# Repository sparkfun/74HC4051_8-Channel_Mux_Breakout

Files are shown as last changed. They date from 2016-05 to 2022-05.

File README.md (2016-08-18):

SparkFun Multiplexer Breakout - 8 Channel (74HC4051)
========================================

SparkFun Multiplexer Breakout - 8 Channel (74HC4051) (https://www.sparkfun.com/products/13906)

[*SparkFun Multiplexer Breakout - 8 Channel (74HC4051) (SKU)*](https://www.sparkfun.com/products/13906)

The SparkFun Multiplexer Breakout provides access to all pins and features of the 74HC4051, an 8-channel analog multiplexer/demultiplexer. The 74HC4051 allows you to turn four I/O pins into eight multi-functional, individually-selectable signals, which can be used do everything from driving eight LEDs to monitoring eight potentiometers.

Repository Contents
-------------------

* **/Firmware** - Example code 
* **/Hardware** - Eagle design files (.brd, .sch)
* **/Production** - Production panel files (.brd)

Documentation
--------------
* **[Hookup Guide](https://learn.sparkfun.com/tutorials/multiplexer-breakout-hookup-guide)** - Basic hookup guide for the Multiplexer Breakout - 8 Channel (74HC4051).
* **[SparkFun Fritzing repo](https://github.com/sparkfun/Fritzing_Parts)** - Fritzing diagrams for SparkFun products.
* **[SparkFun 3D Model repo](https://github.com/sparkfun/3D_Models)** - 3D models of SparkFun products. 

Product Versions
----------------
* [BOB-13906](https://www.sparkfun.com/products/13906)- Basic part and short description here

Version History
---------------
* [v1.0](https://github.com/sparkfun/74HC4051_8-Channel_Mux_Breakout/tree/V_1.0) - Initial hardware release

License Information
-------------------

This product is _**open source**_! 

Please review the LICENSE.md file for license information. 

If you have any questions or concerns on licensing, please contact techsupport@sparkfun.com.

Distributed as-is; no warranty is given.

- Your friends at SparkFun.

_<COLLABORATION CREDIT>_

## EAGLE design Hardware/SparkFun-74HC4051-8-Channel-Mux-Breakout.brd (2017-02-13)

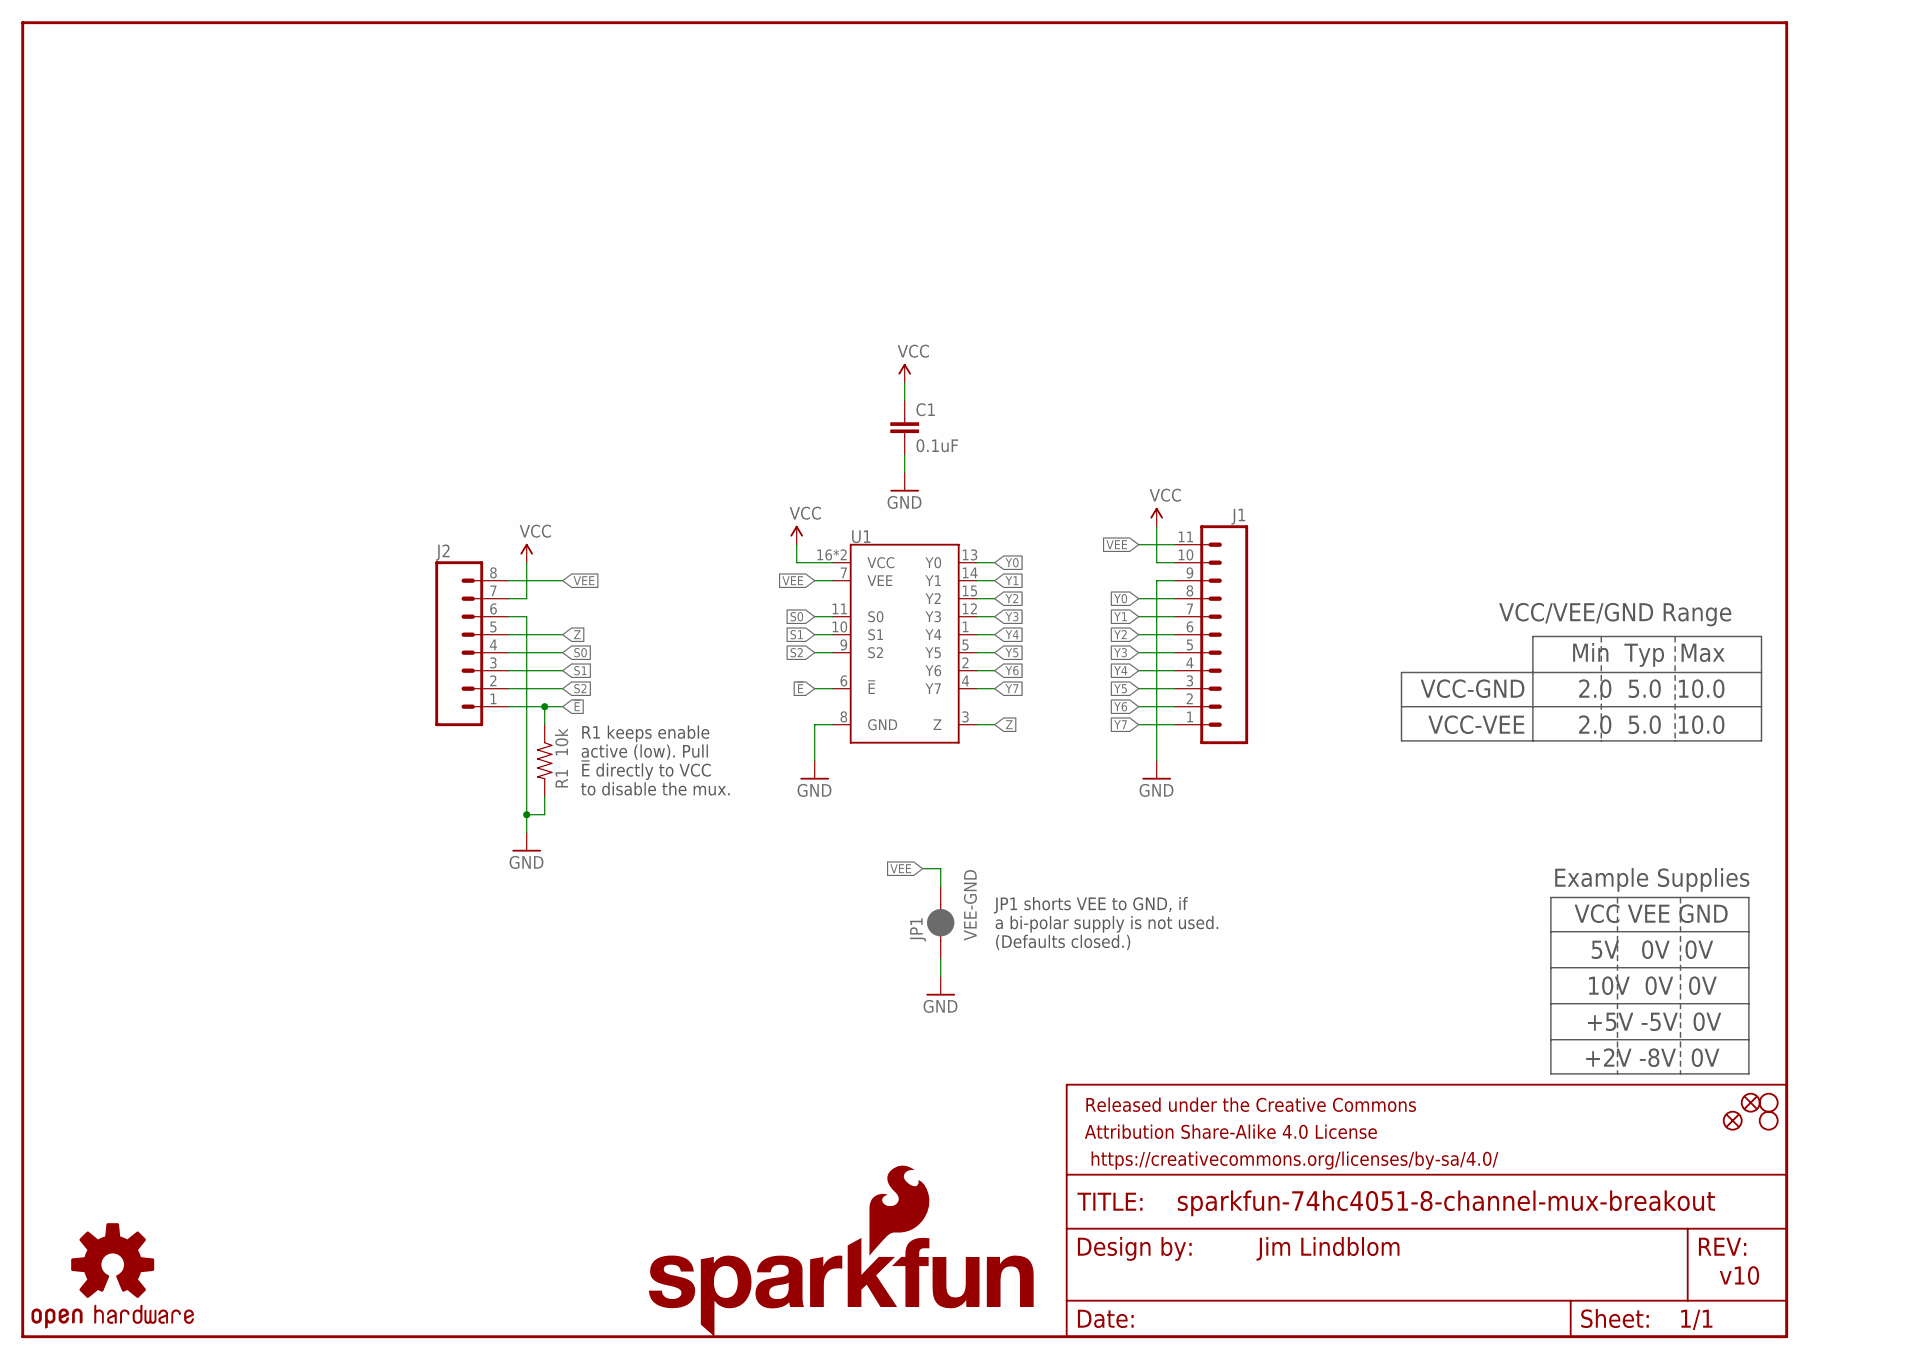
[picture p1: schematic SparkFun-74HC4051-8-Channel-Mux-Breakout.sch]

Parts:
C1: 0.1uF; 0603
FD1, FD2: FIDUCIAL1X2; FIDUCIAL-1X2
FRAME1: FRAME-LETTER; CREATIVE_COMMONS
H1, H2: STAND-OFF
J1: M11PTH; 1X11
J2: M08; 1X08_ROUND
JP1: VEE-GND; PAD-JUMPER-2-NC_BY_PASTE_NO_SILK
LOGO1: SFE_LOGO_FLAME.1_INCH; SFE_LOGO_FLAME_.1
LOGO2: OSHW-LOGOMINI; OSHW-LOGO-MINI
LOGO3: SFE_LOGO_NAME.1_INCH; SFE_LOGO_NAME_.1
R1: 10k; 0603
U1: 74HC4051BQ; DHVQFN-16-2.5X3.5MM

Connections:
!E!: J2.1, R1.1, U1.6 (!E!)
GND: C1.2, J1.9, J2.6, JP1.1, R1.2, U1.8 (GND)
S0: J2.4, U1.11 (S0)
S1: J2.3, U1.10 (S1)
S2: J2.2, U1.9 (S2)
VCC: C1.1, J1.10, J2.7, U1.16 (VCC), U1.EP (VCC)
VEE: J1.11, J2.8, JP1.2, U1.7 (VEE)
Y0: J1.8, U1.13 (Y0)
Y1: J1.7, U1.14 (Y1)
Y2: J1.6, U1.15 (Y2)
Y3: J1.5, U1.12 (Y3)
Y4: J1.4, U1.1 (Y4)
Y5: J1.3, U1.5 (Y5)
Y6: J1.2, U1.2 (Y6)
Y7: J1.1, U1.4 (Y7)
Z: J2.5, U1.3 (Z)

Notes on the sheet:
VCC-GND
VCC-VEE
Min Typ Max
2.0 5.0 10.0
v10
Jim Lindblom
JP1 shorts VEE to GND, if a bi-polar supply is not used. (Defaults closed.)
R1 keeps enable active (low). Pull !E! directly to VCC to disable the mux.
VCC VEE GND
10V 0V 0V
+5V -5V 0V
+2V -8V 0V
5V 0V 0V
Example Supplies
VCC/VEE/GND Range

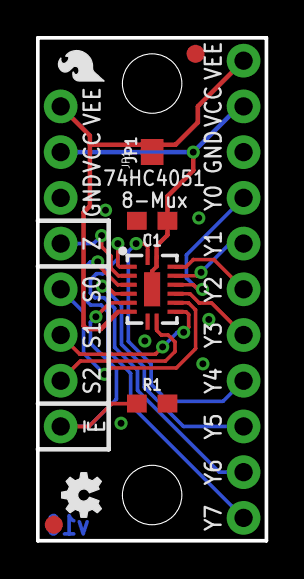
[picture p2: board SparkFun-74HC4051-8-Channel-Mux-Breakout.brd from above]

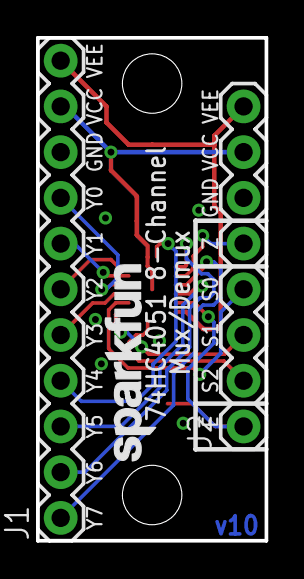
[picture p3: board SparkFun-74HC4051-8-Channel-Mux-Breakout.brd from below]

Board: 2 copper layers, 12.7 x 27.9 mm, 14 parts (3 on the bottom side), 16 nets.

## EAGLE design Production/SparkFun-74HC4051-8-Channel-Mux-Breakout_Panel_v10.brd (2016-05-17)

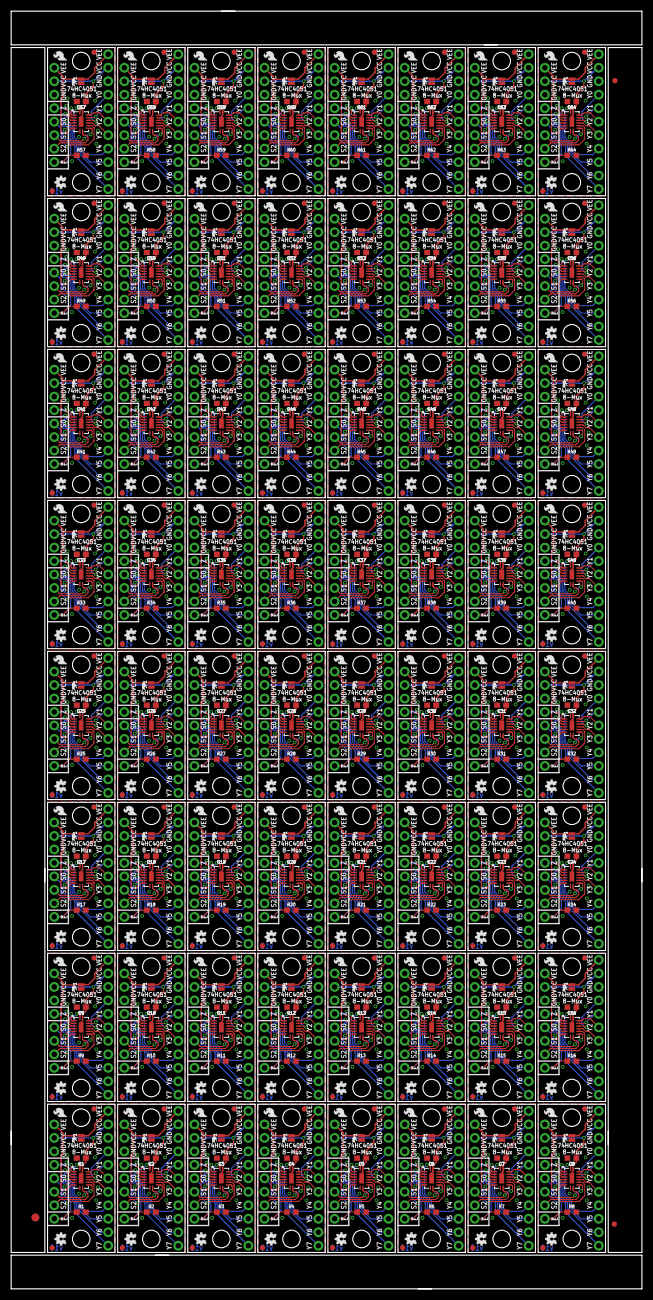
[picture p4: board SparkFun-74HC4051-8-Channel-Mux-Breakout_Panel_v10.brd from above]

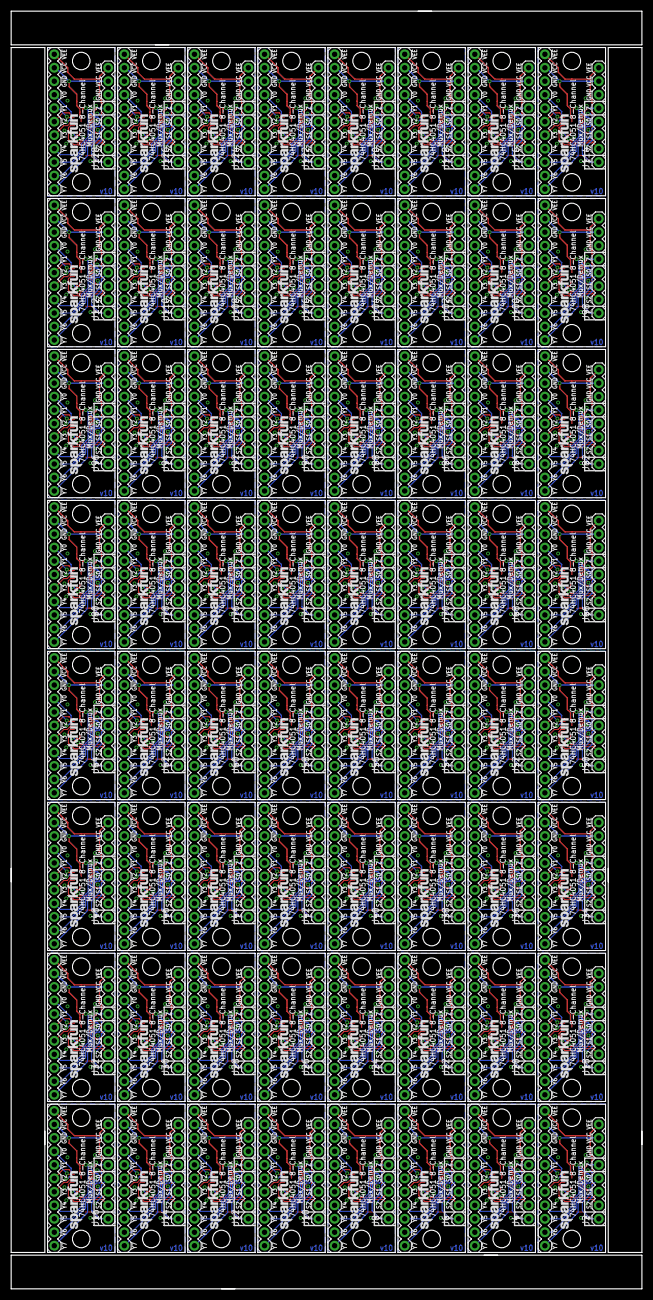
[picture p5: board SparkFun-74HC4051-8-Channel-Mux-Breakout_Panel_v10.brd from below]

Board: 2 copper layers, 118.9 x 240.8 mm, 835 parts (192 on the bottom side), 1024 nets.

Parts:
C1, C2, C3, C4, C5, C6, C7, C8, C9, C10, C11, C12, C13, C14, C15, C16, C17, C18, C19, C20, C21, C22, C23, C24, C25, C26, C27, C28, C29, C30, C31, C32, C33, C34, C35, C36, C37, C38, C39, C40, C41, C42, C43, C44, C45, C46, C47, C48, C49, C50, C51, C52, C53, C54, C55, C56, C57, C58, C59, C60, C61, C62, C63, C64: 0.1uF; 0603
E$1: FIDUCIAL-1.5X3
E$5, E$7: FIDUCIAL-1X2
FD1, FD2, FD3, FD4, FD5, FD6, FD7, FD8, FD9, FD10, FD11, FD12, FD13, FD14, FD15, FD16, FD17, FD18, FD19, FD20, FD21, FD22, FD23, FD24, FD25, FD26, FD27, FD28, FD29, FD30, FD31, FD32, FD33, FD34, FD35, FD36, FD37, FD38, FD39, FD40, FD41, FD42, FD43, FD44, FD45, FD46, FD47, FD48, FD49, FD50, FD51, FD52, FD53, FD54, FD55, FD56, FD57, FD58, FD59, FD60, FD61, FD62, FD63, FD64, FD65, FD66, FD67, FD68, FD69, FD70, FD71, FD72, FD73, FD74, FD75, FD76, FD77, FD78, FD79, FD80, FD81, FD82, FD83, FD84, FD85, FD86, FD87, FD88, FD89, FD90, FD91, FD92, FD93, FD94, FD95, FD96, FD97, FD98, FD99, FD100, FD101, FD102, FD103, FD104, FD105, FD106, FD107, FD108, FD109, FD110, FD111, FD112, FD113, FD114, FD115, FD116, FD117, FD118, FD119, FD120, FD121, FD122, FD123, FD124, FD125, FD126, FD127, FD128: FIDUCIAL1X2; FIDUCIAL-1X2
H1, H2, H3, H4, H5, H6, H7, H8, H9, H10, H11, H12, H13, H14, H15, H16, H17, H18, H19, H20, H21, H22, H23, H24, H25, H26, H27, H28, H29, H30, H31, H32, H33, H34, H35, H36, H37, H38, H39, H40, H41, H42, H43, H44, H45, H46, H47, H48, H49, H50, H51, H52, H53, H54, H55, H56, H57, H58, H59, H60, H61, H62, H63, H64, H65, H66, H67, H68, H69, H70, H71, H72, H73, H74, H75, H76, H77, H78, H79, H80, H81, H82, H83, H84, H85, H86, H87, H88, H89, H90, H91, H92, H93, H94, H95, H96, H97, H98, H99, H100, H101, H102, H103, H104, H105, H106, H107, H108, H109, H110, H111, H112, H113, H114, H115, H116, H117, H118, H119, H120, H121, H122, H123, H124, H125, H126, H127, H128: STAND-OFF
J1, J3, J5, J7, J9, J11, J13, J15, J17, J19, J21, J23, J25, J27, J29, J31, J33, J35, J37, J39, J41, J43, J45, J47, J49, J51, J53, J55, J57, J59, J61, J63, J65, J67, J69, J71, J73, J75, J77, J79, J81, J83, J85, J87, J89, J91, J93, J95, J97, J99, J101, J103, J105, J107, J109, J111, J113, J115, J117, J119, J121, J123, J125, J127: 1X11
J2, J4, J6, J8, J10, J12, J14, J16, J18, J20, J22, J24, J26, J28, J30, J32, J34, J36, J38, J40, J42, J44, J46, J48, J50, J52, J54, J56, J58, J60, J62, J64, J66, J68, J70, J72, J74, J76, J78, J80, J82, J84, J86, J88, J90, J92, J94, J96, J98, J100, J102, J104, J106, J108, J110, J112, J114, J116, J118, J120, J122, J124, J126, J128: 1X08_ROUND
JP1, JP2, JP3, JP4, JP5, JP6, JP7, JP8, JP9, JP10, JP11, JP12, JP13, JP14, JP15, JP16, JP17, JP18, JP19, JP20, JP21, JP22, JP23, JP24, JP25, JP26, JP27, JP28, JP29, JP30, JP31, JP32, JP33, JP34, JP35, JP36, JP37, JP38, JP39, JP40, JP41, JP42, JP43, JP44, JP45, JP46, JP47, JP48, JP49, JP50, JP51, JP52, JP53, JP54, JP55, JP56, JP57, JP58, JP59, JP60, JP61, JP62, JP63, JP64: VEE-GND; PAD-JUMPER-2-NC_BY_PASTE_NO_SILK
LOGO1, LOGO4, LOGO7, LOGO10, LOGO13, LOGO16, LOGO19, LOGO22, LOGO25, LOGO28, LOGO31, LOGO34, LOGO37, LOGO40, LOGO43, LOGO46, LOGO49, LOGO52, LOGO55, LOGO58, LOGO61, LOGO64, LOGO67, LOGO70, LOGO73, LOGO76, LOGO79, LOGO82, LOGO85, LOGO88, LOGO91, LOGO94, LOGO97, LOGO100, LOGO103, LOGO106, LOGO109, LOGO112, LOGO115, LOGO118, LOGO121, LOGO124, LOGO127, LOGO130, LOGO133, LOGO136, LOGO139, LOGO142, LOGO145, LOGO148, LOGO151, LOGO154, LOGO157, LOGO160, LOGO163, LOGO166, LOGO169, LOGO172, LOGO175, LOGO178, LOGO181, LOGO184, LOGO187, LOGO190: SFE_LOGO_FLAME.1_INCH; SFE_LOGO_FLAME_.1
LOGO2, LOGO5, LOGO8, LOGO11, LOGO14, LOGO17, LOGO20, LOGO23, LOGO26, LOGO29, LOGO32, LOGO35, LOGO38, LOGO41, LOGO44, LOGO47, LOGO50, LOGO53, LOGO56, LOGO59, LOGO62, LOGO65, LOGO68, LOGO71, LOGO74, LOGO77, LOGO80, LOGO83, LOGO86, LOGO89, LOGO92, LOGO95, LOGO98, LOGO101, LOGO104, LOGO107, LOGO110, LOGO113, LOGO116, LOGO119, LOGO122, LOGO125, LOGO128, LOGO131, LOGO134, LOGO137, LOGO140, LOGO143, LOGO146, LOGO149, LOGO152, LOGO155, LOGO158, LOGO161, LOGO164, LOGO167, LOGO170, LOGO173, LOGO176, LOGO179, LOGO182, LOGO185, LOGO188, LOGO191: OSHW-LOGOMINI; OSHW-LOGO-MINI
LOGO3, LOGO6, LOGO9, LOGO12, LOGO15, LOGO18, LOGO21, LOGO24, LOGO27, LOGO30, LOGO33, LOGO36, LOGO39, LOGO42, LOGO45, LOGO48, LOGO51, LOGO54, LOGO57, LOGO60, LOGO63, LOGO66, LOGO69, LOGO72, LOGO75, LOGO78, LOGO81, LOGO84, LOGO87, LOGO90, LOGO93, LOGO96, LOGO99, LOGO102, LOGO105, LOGO108, LOGO111, LOGO114, LOGO117, LOGO120, LOGO123, LOGO126, LOGO129, LOGO132, LOGO135, LOGO138, LOGO141, LOGO144, LOGO147, LOGO150, LOGO153, LOGO156, LOGO159, LOGO162, LOGO165, LOGO168, LOGO171, LOGO174, LOGO177, LOGO180, LOGO183, LOGO186, LOGO189, LOGO192: SFE_LOGO_NAME.1_INCH; SFE_LOGO_NAME_.1
R1, R2, R3, R4, R5, R6, R7, R8, R9, R10, R11, R12, R13, R14, R15, R16, R17, R18, R19, R20, R21, R22, R23, R24, R25, R26, R27, R28, R29, R30, R31, R32, R33, R34, R35, R36, R37, R38, R39, R40, R41, R42, R43, R44, R45, R46, R47, R48, R49, R50, R51, R52, R53, R54, R55, R56, R57, R58, R59, R60, R61, R62, R63, R64: 10k; 0603
U1, U2, U3, U4, U5, U6, U7, U8, U9, U10, U11, U12, U13, U14, U15, U16, U17, U18, U19, U20, U21, U22, U23, U24, U25, U26, U27, U28, U29, U30, U31, U32, U33, U34, U35, U36, U37, U38, U39, U40, U41, U42, U43, U44, U45, U46, U47, U48, U49, U50, U51, U52, U53, U54, U55, U56, U57, U58, U59, U60, U61, U62, U63, U64: 74HC4051BQ; DHVQFN-16-2.5X3.5MM

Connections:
!E!: J2.1, R1.1, U1.6
!E!1: J4.1, R2.1, U2.6
!E!2: J6.1, R3.1, U3.6
!E!3: J8.1, R4.1, U4.6
!E!4: J10.1, R5.1, U5.6
!E!5: J12.1, R6.1, U6.6
!E!6: J14.1, R7.1, U7.6
!E!7: J16.1, R8.1, U8.6
!E!8: J18.1, R9.1, U9.6
!E!9: J20.1, R10.1, U10.6
!E!10: J22.1, R11.1, U11.6
!E!11: J24.1, R12.1, U12.6
!E!12: J26.1, R13.1, U13.6
!E!13: J28.1, R14.1, U14.6
!E!14: J30.1, R15.1, U15.6
!E!15: J32.1, R16.1, U16.6
!E!16: J34.1, R17.1, U17.6
!E!17: J36.1, R18.1, U18.6
!E!18: J38.1, R19.1, U19.6
!E!19: J40.1, R20.1, U20.6
!E!20: J42.1, R21.1, U21.6
!E!21: J44.1, R22.1, U22.6
!E!22: J46.1, R23.1, U23.6
!E!23: J48.1, R24.1, U24.6
!E!24: J50.1, R25.1, U25.6
!E!25: J52.1, R26.1, U26.6
!E!26: J54.1, R27.1, U27.6
!E!27: J56.1, R28.1, U28.6
!E!28: J58.1, R29.1, U29.6
!E!29: J60.1, R30.1, U30.6
!E!30: J62.1, R31.1, U31.6
!E!31: J64.1, R32.1, U32.6
!E!32: J66.1, R33.1, U33.6
!E!33: J68.1, R34.1, U34.6
!E!34: J70.1, R35.1, U35.6
!E!35: J72.1, R36.1, U36.6
!E!36: J74.1, R37.1, U37.6
!E!37: J76.1, R38.1, U38.6
!E!38: J78.1, R39.1, U39.6
!E!39: J80.1, R40.1, U40.6
!E!40: J82.1, R41.1, U41.6
!E!41: J84.1, R42.1, U42.6
!E!42: J86.1, R43.1, U43.6
!E!43: J88.1, R44.1, U44.6
!E!44: J90.1, R45.1, U45.6
!E!45: J92.1, R46.1, U46.6
!E!46: J94.1, R47.1, U47.6
!E!47: J96.1, R48.1, U48.6
!E!48: J98.1, R49.1, U49.6
!E!49: J100.1, R50.1, U50.6
!E!50: J102.1, R51.1, U51.6
!E!51: J104.1, R52.1, U52.6
!E!52: J106.1, R53.1, U53.6
!E!53: J108.1, R54.1, U54.6
!E!54: J110.1, R55.1, U55.6
!E!55: J112.1, R56.1, U56.6
!E!56: J114.1, R57.1, U57.6
!E!57: J116.1, R58.1, U58.6
!E!58: J118.1, R59.1, U59.6
!E!59: J120.1, R60.1, U60.6
!E!60: J122.1, R61.1, U61.6
!E!61: J124.1, R62.1, U62.6
!E!62: J126.1, R63.1, U63.6
!E!63: J128.1, R64.1, U64.6
GND: C1.2, J1.9, J2.6, JP1.1, R1.2, U1.8
GND1: C2.2, J3.9, J4.6, JP2.1, R2.2, U2.8
GND2: C3.2, J5.9, J6.6, JP3.1, R3.2, U3.8
GND3: C4.2, J7.9, J8.6, JP4.1, R4.2, U4.8
GND4: C5.2, J9.9, J10.6, JP5.1, R5.2, U5.8
GND5: C6.2, J11.9, J12.6, JP6.1, R6.2, U6.8
GND6: C7.2, J13.9, J14.6, JP7.1, R7.2, U7.8
GND7: C8.2, J15.9, J16.6, JP8.1, R8.2, U8.8
GND8: C9.2, J17.9, J18.6, JP9.1, R9.2, U9.8
GND9: C10.2, J19.9, J20.6, JP10.1, R10.2, U10.8
GND10: C11.2, J21.9, J22.6, JP11.1, R11.2, U11.8
GND11: C12.2, J23.9, J24.6, JP12.1, R12.2, U12.8
GND12: C13.2, J25.9, J26.6, JP13.1, R13.2, U13.8
GND13: C14.2, J27.9, J28.6, JP14.1, R14.2, U14.8
GND14: C15.2, J29.9, J30.6, JP15.1, R15.2, U15.8
GND15: C16.2, J31.9, J32.6, JP16.1, R16.2, U16.8
GND16: C17.2, J33.9, J34.6, JP17.1, R17.2, U17.8
GND17: C18.2, J35.9, J36.6, JP18.1, R18.2, U18.8
GND18: C19.2, J37.9, J38.6, JP19.1, R19.2, U19.8
GND19: C20.2, J39.9, J40.6, JP20.1, R20.2, U20.8
GND20: C21.2, J41.9, J42.6, JP21.1, R21.2, U21.8
GND21: C22.2, J43.9, J44.6, JP22.1, R22.2, U22.8
GND22: C23.2, J45.9, J46.6, JP23.1, R23.2, U23.8
GND23: C24.2, J47.9, J48.6, JP24.1, R24.2, U24.8
GND24: C25.2, J49.9, J50.6, JP25.1, R25.2, U25.8
GND25: C26.2, J51.9, J52.6, JP26.1, R26.2, U26.8
GND26: C27.2, J53.9, J54.6, JP27.1, R27.2, U27.8
GND27: C28.2, J55.9, J56.6, JP28.1, R28.2, U28.8
GND28: C29.2, J57.9, J58.6, JP29.1, R29.2, U29.8
GND29: C30.2, J59.9, J60.6, JP30.1, R30.2, U30.8
GND30: C31.2, J61.9, J62.6, JP31.1, R31.2, U31.8
GND31: C32.2, J63.9, J64.6, JP32.1, R32.2, U32.8
GND32: C33.2, J65.9, J66.6, JP33.1, R33.2, U33.8
GND33: C34.2, J67.9, J68.6, JP34.1, R34.2, U34.8
GND34: C35.2, J69.9, J70.6, JP35.1, R35.2, U35.8
GND35: C36.2, J71.9, J72.6, JP36.1, R36.2, U36.8
GND36: C37.2, J73.9, J74.6, JP37.1, R37.2, U37.8
GND37: C38.2, J75.9, J76.6, JP38.1, R38.2, U38.8
GND38: C39.2, J77.9, J78.6, JP39.1, R39.2, U39.8
GND39: C40.2, J79.9, J80.6, JP40.1, R40.2, U40.8
GND40: C41.2, J81.9, J82.6, JP41.1, R41.2, U41.8
GND41: C42.2, J83.9, J84.6, JP42.1, R42.2, U42.8
GND42: C43.2, J85.9, J86.6, JP43.1, R43.2, U43.8
GND43: C44.2, J87.9, J88.6, JP44.1, R44.2, U44.8
GND44: C45.2, J89.9, J90.6, JP45.1, R45.2, U45.8
GND45: C46.2, J91.9, J92.6, JP46.1, R46.2, U46.8
GND46: C47.2, J93.9, J94.6, JP47.1, R47.2, U47.8
GND47: C48.2, J95.9, J96.6, JP48.1, R48.2, U48.8
GND48: C49.2, J97.9, J98.6, JP49.1, R49.2, U49.8
GND49: C50.2, J99.9, J100.6, JP50.1, R50.2, U50.8
GND50: C51.2, J101.9, J102.6, JP51.1, R51.2, U51.8
GND51: C52.2, J103.9, J104.6, JP52.1, R52.2, U52.8
GND52: C53.2, J105.9, J106.6, JP53.1, R53.2, U53.8
GND53: C54.2, J107.9, J108.6, JP54.1, R54.2, U54.8
GND54: C55.2, J109.9, J110.6, JP55.1, R55.2, U55.8
GND55: C56.2, J111.9, J112.6, JP56.1, R56.2, U56.8
GND56: C57.2, J113.9, J114.6, JP57.1, R57.2, U57.8
GND57: C58.2, J115.9, J116.6, JP58.1, R58.2, U58.8
GND58: C59.2, J117.9, J118.6, JP59.1, R59.2, U59.8
GND59: C60.2, J119.9, J120.6, JP60.1, R60.2, U60.8
GND60: C61.2, J121.9, J122.6, JP61.1, R61.2, U61.8
GND61: C62.2, J123.9, J124.6, JP62.1, R62.2, U62.8
GND62: C63.2, J125.9, J126.6, JP63.1, R63.2, U63.8
GND63: C64.2, J127.9, J128.6, JP64.1, R64.2, U64.8
S0: J2.4, U1.11
S1: J2.3, U1.10
S2: J2.2, U1.9
S3: J4.2, U2.9
S4: J4.4, U2.11
S5: J4.3, U2.10
S6: J6.2, U3.9
S7: J6.4, U3.11
S8: J6.3, U3.10
S9: J8.2, U4.9
S10: J8.4, U4.11
S11: J8.3, U4.10
S12: J10.2, U5.9
S13: J10.4, U5.11
S14: J10.3, U5.10
S15: J12.2, U6.9
S16: J12.4, U6.11
S17: J12.3, U6.10
S18: J14.2, U7.9
S19: J14.4, U7.11
S20: J14.3, U7.10
S21: J16.2, U8.9
S22: J16.4, U8.11
S23: J16.3, U8.10
S24: J18.2, U9.9
S25: J18.4, U9.11
S26: J18.3, U9.10
S27: J20.2, U10.9
S28: J20.4, U10.11
S29: J20.3, U10.10
S30: J22.2, U11.9
S31: J22.4, U11.11
S32: J22.3, U11.10
S33: J24.2, U12.9
S34: J24.4, U12.11
S35: J24.3, U12.10
S36: J26.2, U13.9
S37: J26.4, U13.11
S38: J26.3, U13.10
S39: J28.2, U14.9
S40: J28.4, U14.11
S41: J28.3, U14.10
S42: J30.2, U15.9
S43: J30.4, U15.11
S44: J30.3, U15.10
S45: J32.2, U16.9
S46: J32.4, U16.11
S47: J32.3, U16.10
S48: J34.2, U17.9
S49: J34.4, U17.11
S50: J34.3, U17.10
S51: J36.2, U18.9
S52: J36.4, U18.11
S53: J36.3, U18.10
S54: J38.2, U19.9
S55: J38.4, U19.11
S56: J38.3, U19.10
S57: J40.2, U20.9
S58: J40.4, U20.11
S59: J40.3, U20.10
S60: J42.2, U21.9
S61: J42.4, U21.11
S62: J42.3, U21.10
S63: J44.2, U22.9
S64: J44.4, U22.11
S65: J44.3, U22.10
S66: J46.2, U23.9
S67: J46.4, U23.11
S68: J46.3, U23.10
S69: J48.2, U24.9
S70: J48.4, U24.11
S71: J48.3, U24.10
S72: J50.2, U25.9
S73: J50.4, U25.11
S74: J50.3, U25.10
S75: J52.2, U26.9
S76: J52.4, U26.11
S77: J52.3, U26.10
S78: J54.2, U27.9
S79: J54.4, U27.11
S80: J54.3, U27.10
S81: J56.2, U28.9
S82: J56.4, U28.11
S83: J56.3, U28.10
S84: J58.2, U29.9
S85: J58.4, U29.11
S86: J58.3, U29.10
S87: J60.2, U30.9
S88: J60.4, U30.11
S89: J60.3, U30.10
S90: J62.2, U31.9
S91: J62.4, U31.11
S92: J62.3, U31.10
S93: J64.2, U32.9
S94: J64.4, U32.11
S95: J64.3, U32.10
S96: J66.2, U33.9
S97: J66.4, U33.11
S98: J66.3, U33.10
S99: J68.2, U34.9
S100: J68.4, U34.11
S101: J68.3, U34.10
S102: J70.2, U35.9
S103: J70.4, U35.11
S104: J70.3, U35.10
S105: J72.2, U36.9
S106: J72.4, U36.11
S107: J72.3, U36.10
S108: J74.2, U37.9
S109: J74.4, U37.11
S110: J74.3, U37.10
S111: J76.2, U38.9
S112: J76.4, U38.11
S113: J76.3, U38.10
S114: J78.2, U39.9
S115: J78.4, U39.11
S116: J78.3, U39.10
S117: J80.2, U40.9
S118: J80.4, U40.11
S119: J80.3, U40.10
S120: J82.2, U41.9
S121: J82.4, U41.11
S122: J82.3, U41.10
S123: J84.2, U42.9
S124: J84.4, U42.11
S125: J84.3, U42.10
S126: J86.2, U43.9
S127: J86.4, U43.11
S128: J86.3, U43.10
S129: J88.2, U44.9
S130: J88.4, U44.11
S131: J88.3, U44.10
S132: J90.2, U45.9
S133: J90.4, U45.11
S134: J90.3, U45.10
S135: J92.2, U46.9
S136: J92.4, U46.11
S137: J92.3, U46.10
S138: J94.2, U47.9
S139: J94.4, U47.11
S140: J94.3, U47.10
S141: J96.2, U48.9
S142: J96.4, U48.11
S143: J96.3, U48.10
S144: J98.2, U49.9
S145: J98.4, U49.11
S146: J98.3, U49.10
S147: J100.2, U50.9
S148: J100.4, U50.11
S149: J100.3, U50.10
S150: J102.2, U51.9
S151: J102.4, U51.11
S152: J102.3, U51.10
S153: J104.2, U52.9
S154: J104.4, U52.11
S155: J104.3, U52.10
S156: J106.2, U53.9
S157: J106.4, U53.11
S158: J106.3, U53.10
S159: J108.2, U54.9
S160: J108.4, U54.11
S161: J108.3, U54.10
S162: J110.2, U55.9
S163: J110.4, U55.11
S164: J110.3, U55.10
S165: J112.2, U56.9
S166: J112.4, U56.11
S167: J112.3, U56.10
S168: J114.2, U57.9
S169: J114.4, U57.11
S170: J114.3, U57.10
S171: J116.2, U58.9
S172: J116.4, U58.11
S173: J116.3, U58.10
S174: J118.2, U59.9
S175: J118.4, U59.11
S176: J118.3, U59.10
S177: J120.2, U60.9
S178: J120.4, U60.11
S179: J120.3, U60.10
S180: J122.2, U61.9
S181: J122.4, U61.11
S182: J122.3, U61.10
S183: J124.2, U62.9
S184: J124.4, U62.11
S185: J124.3, U62.10
S186: J126.2, U63.9
S187: J126.4, U63.11
S188: J126.3, U63.10
S189: J128.2, U64.9
S190: J128.4, U64.11
S191: J128.3, U64.10
VCC: C1.1, J1.10, J2.7, U1.16, U1.EP
VCC1: C2.1, J3.10, J4.7, U2.16, U2.EP
VCC2: C3.1, J5.10, J6.7, U3.16, U3.EP
VCC3: C4.1, J7.10, J8.7, U4.16, U4.EP
VCC4: C5.1, J9.10, J10.7, U5.16, U5.EP
VCC5: C6.1, J11.10, J12.7, U6.16, U6.EP
VCC6: C7.1, J13.10, J14.7, U7.16, U7.EP
VCC7: C8.1, J15.10, J16.7, U8.16, U8.EP
VCC8: C9.1, J17.10, J18.7, U9.16, U9.EP
VCC9: C10.1, J19.10, J20.7, U10.16, U10.EP
VCC10: C11.1, J21.10, J22.7, U11.16, U11.EP
VCC11: C12.1, J23.10, J24.7, U12.16, U12.EP
VCC12: C13.1, J25.10, J26.7, U13.16, U13.EP
VCC13: C14.1, J27.10, J28.7, U14.16, U14.EP
VCC14: C15.1, J29.10, J30.7, U15.16, U15.EP
VCC15: C16.1, J31.10, J32.7, U16.16, U16.EP
VCC16: C17.1, J33.10, J34.7, U17.16, U17.EP
VCC17: C18.1, J35.10, J36.7, U18.16, U18.EP
VCC18: C19.1, J37.10, J38.7, U19.16, U19.EP
VCC19: C20.1, J39.10, J40.7, U20.16, U20.EP
VCC20: C21.1, J41.10, J42.7, U21.16, U21.EP
VCC21: C22.1, J43.10, J44.7, U22.16, U22.EP
VCC22: C23.1, J45.10, J46.7, U23.16, U23.EP
VCC23: C24.1, J47.10, J48.7, U24.16, U24.EP
VCC24: C25.1, J49.10, J50.7, U25.16, U25.EP
VCC25: C26.1, J51.10, J52.7, U26.16, U26.EP
VCC26: C27.1, J53.10, J54.7, U27.16, U27.EP
VCC27: C28.1, J55.10, J56.7, U28.16, U28.EP
VCC28: C29.1, J57.10, J58.7, U29.16, U29.EP
VCC29: C30.1, J59.10, J60.7, U30.16, U30.EP
VCC30: C31.1, J61.10, J62.7, U31.16, U31.EP
VCC31: C32.1, J63.10, J64.7, U32.16, U32.EP
VCC32: C33.1, J65.10, J66.7, U33.16, U33.EP
VCC33: C34.1, J67.10, J68.7, U34.16, U34.EP
VCC34: C35.1, J69.10, J70.7, U35.16, U35.EP
VCC35: C36.1, J71.10, J72.7, U36.16, U36.EP
VCC36: C37.1, J73.10, J74.7, U37.16, U37.EP
VCC37: C38.1, J75.10, J76.7, U38.16, U38.EP
VCC38: C39.1, J77.10, J78.7, U39.16, U39.EP
VCC39: C40.1, J79.10, J80.7, U40.16, U40.EP
VCC40: C41.1, J81.10, J82.7, U41.16, U41.EP
VCC41: C42.1, J83.10, J84.7, U42.16, U42.EP
VCC42: C43.1, J85.10, J86.7, U43.16, U43.EP
VCC43: C44.1, J87.10, J88.7, U44.16, U44.EP
VCC44: C45.1, J89.10, J90.7, U45.16, U45.EP
VCC45: C46.1, J91.10, J92.7, U46.16, U46.EP
VCC46: C47.1, J93.10, J94.7, U47.16, U47.EP
VCC47: C48.1, J95.10, J96.7, U48.16, U48.EP
VCC48: C49.1, J97.10, J98.7, U49.16, U49.EP
VCC49: C50.1, J99.10, J100.7, U50.16, U50.EP
VCC50: C51.1, J101.10, J102.7, U51.16, U51.EP
VCC51: C52.1, J103.10, J104.7, U52.16, U52.EP
VCC52: C53.1, J105.10, J106.7, U53.16, U53.EP
VCC53: C54.1, J107.10, J108.7, U54.16, U54.EP
VCC54: C55.1, J109.10, J110.7, U55.16, U55.EP
VCC55: C56.1, J111.10, J112.7, U56.16, U56.EP
VCC56: C57.1, J113.10, J114.7, U57.16, U57.EP
VCC57: C58.1, J115.10, J116.7, U58.16, U58.EP
VCC58: C59.1, J117.10, J118.7, U59.16, U59.EP
VCC59: C60.1, J119.10, J120.7, U60.16, U60.EP
VCC60: C61.1, J121.10, J122.7, U61.16, U61.EP
VCC61: C62.1, J123.10, J124.7, U62.16, U62.EP
VCC62: C63.1, J125.10, J126.7, U63.16, U63.EP
VCC63: C64.1, J127.10, J128.7, U64.16, U64.EP
VEE: J1.11, J2.8, JP1.2, U1.7
VEE1: J3.11, J4.8, JP2.2, U2.7
VEE2: J5.11, J6.8, JP3.2, U3.7
VEE3: J7.11, J8.8, JP4.2, U4.7
VEE4: J9.11, J10.8, JP5.2, U5.7
VEE5: J11.11, J12.8, JP6.2, U6.7
VEE6: J13.11, J14.8, JP7.2, U7.7
VEE7: J15.11, J16.8, JP8.2, U8.7
VEE8: J17.11, J18.8, JP9.2, U9.7
VEE9: J19.11, J20.8, JP10.2, U10.7
VEE10: J21.11, J22.8, JP11.2, U11.7
VEE11: J23.11, J24.8, JP12.2, U12.7
VEE12: J25.11, J26.8, JP13.2, U13.7
VEE13: J27.11, J28.8, JP14.2, U14.7
VEE14: J29.11, J30.8, JP15.2, U15.7
VEE15: J31.11, J32.8, JP16.2, U16.7
VEE16: J33.11, J34.8, JP17.2, U17.7
VEE17: J35.11, J36.8, JP18.2, U18.7
VEE18: J37.11, J38.8, JP19.2, U19.7
VEE19: J39.11, J40.8, JP20.2, U20.7
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

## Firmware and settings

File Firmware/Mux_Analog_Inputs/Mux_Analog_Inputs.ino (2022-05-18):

/******************************************************************************
Mux_Analog_Input
SparkFun Multiplexer Analog Input Example
Jim Lindblom @ SparkFun Electronics
August 15, 2016
https://github.com/sparkfun/74HC4051_8-Channel_Mux_Breakout

This sketch demonstrates how to use the SparkFun Multiplexer
Breakout - 8 Channel (74HC4051) to read eight, separate
analog inputs, using just a single ADC channel.

Hardware Hookup:
Mux Breakout ----------- Arduino
     S0 ------------------- 2
     S1 ------------------- 3
     S2 ------------------- 4
     Z -------------------- A0
    VCC ------------------- 5V
    GND ------------------- GND
    (VEE should be connected to GND)

The multiplexers independent I/O (Y0-Y7) can each be wired
up to a potentiometer or any other analog signal-producing
component.

Development environment specifics:
Arduino 1.6.9
SparkFun Multiplexer Breakout - 8-Channel(74HC4051) v10
(https://www.sparkfun.com/products/13906)
******************************************************************************/
/////////////////////
// Pin Definitions //
/////////////////////
const int selectPins[3] = {2, 3, 4}; // S0~2, S1~3, S2~4
const int zOutput = 5; 
const int zInput = A0; // Connect common (Z) to A0 (analog input)

void setup() 
{
  Serial.begin(9600); // Initialize the serial port
  // Set up the select pins as outputs:
  for (int i=0; i<3; i++)
  {
    pinMode(selectPins[i], OUTPUT);
    digitalWrite(selectPins[i], HIGH);
  }
  pinMode(zInput, INPUT); // Set up Z as an input

  // Print the header:
  Serial.println("Y0\tY1\tY2\tY3\tY4\tY5\tY6\tY7");
  Serial.println("---\t---\t---\t---\t---\t---\t---\t---");
}

void loop() 
{
  // Loop through all eight pins.
  for (byte pin=0; pin<=7; pin++)
  {
    selectMuxPin(pin); // Select one at a time
    int inputValue = analogRead(zInput); // and read Z
    Serial.print(String(inputValue) + "\t");
  }
  Serial.println();
  delay(1000);
}

// The selectMuxPin function sets the S0, S1, and S2 pins
// accordingly, given a pin from 0-7.
void selectMuxPin(byte pin)
{
  for (int i=0; i<3; i++)
  {
    if (pin & (1<<i))
      digitalWrite(selectPins[i], HIGH);
    else
      digitalWrite(selectPins[i], LOW);
  }
}

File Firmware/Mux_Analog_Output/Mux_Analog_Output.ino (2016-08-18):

/******************************************************************************
Mux_Analog_Output
SparkFun Multiplexer Output Example
Jim Lindblom @ SparkFun Electronics
August 15, 2016
https://github.com/sparkfun/74HC4051_8-Channel_Mux_Breakout

This sketch demonstrates how to use the SparkFun Multiplexer
Breakout - 8 Channel (74HC4051) to drive eight outputs using
four digital pins.

Hardware Hookup:
Mux Breakout ----------- Arduino
     S0 ------------------- 2
     S1 ------------------- 3
     S2 ------------------- 4
     Z -------------------- 5
    VCC ------------------- 5V
    GND ------------------- GND
    (VEE should be connected to GND)

Development environment specifics:
Arduino 1.6.9
SparkFun Multiplexer Breakout - 8-Channel(74HC4051) v10
(https://www.sparkfun.com/products/13906)
******************************************************************************/
/////////////////////
// Pin Definitions //
/////////////////////
const int selectPins[3] = {2, 3, 4}; // S0~2, S1~3, S2~4
const int zOutput = 5; // Connect common (Z) to 5 (PWM-capable)

const int LED_ON_TIME = 500; // Each LED is on 0.5s
const int DELAY_TIME = ((float)LED_ON_TIME/512.0)*1000;
void setup() 
{
  // Set up the select pins, as outputs
  for (int i=0; i<3; i++)
  {
    pinMode(selectPins[i], OUTPUT);
    digitalWrite(selectPins[i], LOW);
  }
  pinMode(zOutput, OUTPUT); // Set up Z as an output
}

void loop() 
{
  // Cycle from pins Y0 to Y7 first
  for (int pin=0; pin<=7; pin++)
  {
    // Set the S0, S1, and S2 pins to select our active
    // output (Y0-Y7):
    selectMuxPin(pin);
    // While the output is selected ramp the LED intensity up
    for (int intensity=0; intensity<=255; intensity++)
    {
      analogWrite(zOutput, intensity);
      delayMicroseconds(DELAY_TIME);
    }
    // Then bring the analog output value down:
    for (int intensity=255; intensity>=0; intensity--)
    {
      analogWrite(zOutput, intensity);
      delayMicroseconds(DELAY_TIME);
    }
  }
  // Now cycle from pins Y6 to Y1
  for (int pin=6; pin>=1; pin--)
  {
    selectMuxPin(pin); // Select the pin
    // Cycle the intensity up:
    for (int intensity=0; intensity<=255; intensity++)
    {
      analogWrite(zOutput, intensity);
      delayMicroseconds(DELAY_TIME);
    }
    // Then ramp the output down:
    for (int intensity=255; intensity>=0; intensity--)
    {
      analogWrite(zOutput, intensity);
      delayMicroseconds(DELAY_TIME);
    }
  }
}

// The selectMuxPin function sets the S0, S1, and S2 pins
// accordingly, given a pin from 0-7.
void selectMuxPin(byte pin)
{
  if (pin > 7) return; // Exit if pin is out of scope
  for (int i=0; i<3; i++)
  {
    if (pin & (1<<i))
      digitalWrite(selectPins[i], HIGH);
    else
      digitalWrite(selectPins[i], LOW);
  }
}

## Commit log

2016-04-18 Initial commit of hardware
    [SparkFun-74HC4051-8-Channel-Mux-Breakout.brd, SparkFun-74HC4051-8-Channel-Mux-Breakout.sch]
2016-04-21 Resolving issues flagged on issue 1.
    [SparkFun-74HC4051-8-Channel-Mux-Breakout.brd, SparkFun-74HC4051-8-Channel-Mux-Breakout.sch]
2016-04-21 Few changes after running the checklist.
    [SparkFun-74HC4051-8-Channel-Mux-Breakout.brd, SparkFun-74HC4051-8-Channel-Mux-Breakout.sch]
2016-05-16 Fixing silkscreen, upping to v10
    [SparkFun-74HC4051-8-Channel-Mux-Breakout.brd, SparkFun-74HC4051-8-Channel-Mux-Breakout.sch]
2016-05-16 Swapping 100k resistor out with 10k
    [SparkFun-74HC4051-8-Channel-Mux-Breakout.brd, SparkFun-74HC4051-8-Channel-Mux-Breakout.sch]
2016-05-16 Schematic cleanup.
    [SparkFun-74HC4051-8-Channel-Mux-Breakout.sch]
2016-05-17 created panel v10
    [SparkFun-74HC4051-8-Channel-Mux-Breakout_Panel_v10.brd]
2016-08-15 Bumping 0-width tDoc polygons up to 0.1mil.
    [SparkFun-74HC4051-8-Channel-Mux-Breakout.brd, SparkFun-74HC4051-8-Channel-Mux-Breakout.sch]
2016-08-18 Adding example Arduino sketches.
2017-02-13 Used improved SparkFun libraries to remove the need for separate library. Removed single part library. Resolves #3
    [SparkFun-74HC4051-8-Channel-Mux-Breakout.brd, SparkFun-74HC4051-8-Channel-Mux-Breakout.sch]
2022-05-18 Update Mux_Analog_Inputs.ino
    The changes in the code does the same thing but uses the defined variable for A0 to avoid confusion based on customer feedback.
    [Mux_Analog_Inputs.ino]

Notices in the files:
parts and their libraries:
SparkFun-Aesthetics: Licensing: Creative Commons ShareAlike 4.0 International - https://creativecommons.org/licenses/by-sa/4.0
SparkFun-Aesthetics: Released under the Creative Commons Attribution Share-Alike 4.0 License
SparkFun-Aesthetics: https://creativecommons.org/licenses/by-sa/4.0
